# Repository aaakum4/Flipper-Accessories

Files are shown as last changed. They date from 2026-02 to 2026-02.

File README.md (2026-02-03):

# Flipper-Accessories
Now that I have made a custom Flipper, I use create some accessories for it to go with.

A custom expansion board for the Flipper Zero that adds WiFi capability and a high-power IR blaster, designed with safety, flexibility, and future expansion in mind.

This project was designed specifically for my custom Flipper Zero build, which can be found here:
https://github.com/aaakum4/Sorta-Flipper-Zero

While the designs and files are shared openly, they should not be blindly copied or connected to a stock Flipper Zero without understanding the electrical implications. Component choices, power rails, and protection methods were selected with my particular setup and use case in mind.
If you choose to reuse or adapt any part of this project, please make sure it will work with whatever device you are using.

## Overview
This project combines two main subsystems:
- A WiFi board built around the ESP32-S2-WROVER-N4R2 for networking and future firmware experiments
- A 960 nm IR blaster designed for high-power pulsed output while keeping the Flipper electrically isolated

The goal wasn’t just to make something that works, but to make something that’s understandable, modifiable, and safe to plug into a Flipper.

## The WiFi Board
The WiFi side uses the ESP32-S2-WROVER-N4R2, which offered more than enough performance without being unnecessarily complex. Since this board is meant to be reused and extended, several design choices were made with development and debugging in mind:
- Spare GPIO pins left uncommitted for future features
- JTAG and UART exposed for debugging and flashing
- Dedicated BOOT and RESET buttons to avoid relying on awkward software-only recovery

Rather than pushing for maximum performance, the focus here was reliability, ease of development, and not boxing the design into a single use case.

## IR Blaster
The IR blaster uses seven 960 nm IR LEDs, arranged as three series pairs plus one standalone LED, which allowed higher optical output while still working comfortably from a 5 V rail.

A logic-level MOSFET is used for switching instead of a transistor, keeping all high current paths away from the Flipper’s GPIO pins and allowing clean, efficient pulsed operation. The circuit is intended for modulated IR (rather than continuous drive), which makes higher peak currents practical without excessive heat.

This part of the design involved a lot of trade-offs around current, voltage, and safety, and ended up being more conceptually challenging than the WiFi board despite using fewer components.

## Safety & Protection
A core design requirement was ensuring that the Flipper Zero is not put at risk, even in the event of a fault or design mistake. To that end:
- GPIO pins are only ever used as logic-level control signals
- High-current loads are fully isolated using switching components
- Current is limited where appropriate
- No direct power paths exist that could back-feed into the Flipper

The aim was to make the board something you can plug in without constantly worrying about damaging the host device.

## Making the PCB
Here is the final Wifi PCB:




Here is the final IR Blaster PCB:




## BOM
For those interested in the part's I am using, here is the Bill of Materials. It doesnt include the MCU (since it was out of stock when I last check on JLCPCB) and the IR LED's, but any 940nm or 960nm IR LED will do as long as it is 5mm.
Screenshot 2026-02-03 at 1 41 27 pm

## Final Note
Since this is a Flipper project, I feel like I must say that these devices shouldn't be use for any illgeal or unethical activities.

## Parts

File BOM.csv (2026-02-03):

Comment | Designator | Footprint | JLCPCB Part #
100k | R18,R19,R20,R21,R22,R23,R24,R25 | 0201 | C270364
USB_C_Plug | P1 | SMD | C165948
510 | R4 | 0201 | C18164337
100nf | C3,C5 | 0201 | C76934
AZ1117-3.3 | U2 | SOT-223 | C7432020
4.7k | R16,R17 | 0201 | C270346
5.1k | R5,R6 | 0201 | C270344
Si1308EDL | Q1,Q2 | SOT-323 | C7603347
Q_Dual_PNP_PNP_E1B1C2E2B2C1 | Q11,Q6,Q8,Q9 | SOT-363 | C154783
150 | R12,R13,R14,R3 | 0201 | C7467287
D_TVS | D2,D3,D4,D5,D6 | 0201 | C521888
100 | R2 | 0201 | C304499
SW_Push | SW1,SW2 | SMD,3.9x2.9mm | C202388
22uF | C1,C6 | 0603 | C59461
1uF | C4 | 0603 | C15849
LED_RGB | D1 | SMD5050-8P | C6795892
10k | R1,R10,R11,R15 | 0603 | C25804
20 | R7,R8 | 0201 | C320753
Q_PMOS_GSD | Q10,Q12,Q3,Q4,Q5,Q7 | SOT-23-3 | C968645
10uF | C2 | 0603 | C19702
Comment | Designator | Footprint | JLCPCB Part #
5.6 | R2,R3,R4 | 1206 | C137246
Q_NMOS_GSD(RDsON) | Q5 | SOT-23 | C78755
100k | R5 | 603 | C25803
12 | R1 | 1206 | C17913
470 | R7 | 603 | C23179

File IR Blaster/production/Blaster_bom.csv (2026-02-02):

Designator | Footprint | Quantity | Value | LCSC Part #
A1 | Flipper_Zero_Angled | 1 | Flipper_Zero
D1, D2, D3, D4, D5, D6, D7 | LED_D5.0mm | 7 | IR_LED_960nm
Q5 | SOT-23 | 1 | Q_NMOS_GSD (RDs ON)
R1 | 1206 | 1 | 12
R2, R3, R4 | 1206 | 3 | 5.6
R5 | 0603 | 1 | 100k
R7 | 0603 | 1 | 470

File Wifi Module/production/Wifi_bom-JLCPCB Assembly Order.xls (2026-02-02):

JLCPCB BOM Tool - BOM Matching
BOM name：Wifi_bom-JLCPCB Assembly Order.xlsx |  |  | Download Time：2026-02-02 17:04:33 |  |  |  | * Our matching results are updated in real-time, but stock and prices may change. If it's been over 24 hours, please re-match before placing your order.
PCB Assembled Qty：5 |  |  | Est. Total Price：5.3926
Your BOM |  |  |  |  | Matched Parts |  |  |  |  |  |  | Order Information
Top Designator | Bottom Designator | Comment | Footprint | JLCPCB Part # | Matches | Part # | Manufacturer | Footprint | Description | Category | Warning | JLCPCB Part # | Product link | Lib Type | Qty | Source | Total Price ($)
C1,C6 |  | 22uF | 0603 |  | Select by System | CL10A226MQ8NRNC | Samsung Electro-Mechanics | 0603 | 22uF 6.3V X5R ±20% 0603 Multilayer Ceramic Capacitors MLCC - SMD/SMT ROHS | Multilayer Ceramic Capacitors MLCC - SMD/SMT |  | C59461 | https://jlcpcb.com/partdetail/60514-CL10A226MQ8NRNC/C59461 | Basic | 20 | 20 JLCPCB | 0.186
C2 |  | 10uF | 0603 |  | Select by System | CL10A106KP8NNNC | Samsung Electro-Mechanics | 0603 | 10V 10uF X5R ±10% 0603 Multilayer Ceramic Capacitors MLCC - SMD/SMT ROHS | Multilayer Ceramic Capacitors MLCC - SMD/SMT |  | C19702 | https://jlcpcb.com/partdetail/20411-CL10A106KP8NNNC/C19702 | Basic | 20 | 20 JLCPCB | 0.13
C3,C5 |  | 100nf | 0201 |  | Select by System | GRM033R61A104KE15D | Murata Electronics | 0201 | 100nF 10V X5R ±10% 0201 Multilayer Ceramic Capacitors MLCC - SMD/SMT ROHS | Multilayer Ceramic Capacitors MLCC - SMD/SMT |  | C76934 | https://jlcpcb.com/partdetail/MurataElectronics-GRM033R61A104KE15D/C76934 | Extended | 20 | 20 JLCPCB | 0.022
C4 |  | 1uF | 0603 |  | Select by System | CL10A105KB8NNNC | Samsung Electro-Mechanics | 0603 | 1uF 50V X5R ±10% 0603 Multilayer Ceramic Capacitors MLCC - SMD/SMT ROHS | Multilayer Ceramic Capacitors MLCC - SMD/SMT |  | C15849 | https://jlcpcb.com/partdetail/16531-CL10A105KB8NNNC/C15849 | Basic | 20 | 20 JLCPCB | 0.11
D1 |  | LED_RGB | LED_Avago_PLCC6_3x2.8mm |  | Select by Customer | TC5050RGBW3D06-4CSAR3-AFW324A | TCWIN | SMD5050-8P | -40℃~+85℃ 200mW 20mA 2800K~3200K 2V~2.4V、2.8V~3.2V、2.8V~3.2V、2.8V~3.2V 460nm~465nm、515nm~520nm、620nm~625nm 500mcd、700mcd、1.8cd Discrete Diode Red, Emerald Green, Blue, White SMD5050-8P LED Indication - Discrete ROHS | LED Indication - Discrete |  | C784543 | https://jlcpcb.com/partdetail/TCWIN-TC5050RGBW3D06_4CSAR3AFW324A/C784543 | Extended | 2 | 2 JLCPCB | 0.1404
D2,D3,D4,D5,D6 |  | D_TVS | 0201 |  | Select by Customer | ESD3V3U04-0201 | TECH PUBLIC | 0201 | 0.4pF 150nA 16A@8/20us 3.3V 6.5V 8V ESD IEC 61000-4-2、IEC 61000-4-5、IEC 61000-4-4 0201 ESD and Surge Protection (TVS/ESD) ROHS | ESD And Surge Protection (TVS/ESD) |  | C521888 | https://jlcpcb.com/partdetail/TECHPUBLIC-ESD3V3U040201/C521888 | Extended | 20 | 20 JLCPCB | 0.776
P1 |  | USB_C_Plug | USB_C_Receptacle_HRO_TYPE-C-31-M-12 |  | Select by Customer | TYPE-C-31-M-12 | Korean Hroparts Elec | SMD | -30℃~+80℃ 1 10,000 cycles 16P 20V 5A 7.35mm Female Surface Mount, Right Angle Type-C SMD USB Connectors ROHS | USB Connectors |  | C165948 | https://jlcpcb.com/partdetail/Korean_HropartsElec-TYPE_C_31_M12/C165948 | Extended | 2 | 2 JLCPCB | 0.3548
Q1,Q2 |  | Si1308EDL | SOT-323_SC-70 |  | Select by System | SI1308EDL | TECH PUBLIC | SOT-323 | -55℃~+150℃ 1 N-channel 1.4A 1.5V 14.8pF 146pF 150mΩ@4.5V 18.3pF 2.6nC@4.5V 30V 360mW SOT-323 MOSFETs ROHS | MOSFETs |  | C7603347 | https://jlcpcb.com/partdetail/TECHPUBLIC-SI1308EDL/C7603347 | Extended | 8 | 8 JLCPCB | 0.7
Q10,Q12,Q3,Q4,Q5,Q7 |  | Q_PMOS_GSD | SOT-23 |  | Select by Customer | GSD2004S-E3-08 | Vishay Intertech | SOT-23-3 | 1 Pair Series Connection 100nA 1V@100mA 225mA 240V 350mW 4A 50ns SOT-23-3 Switching Diodes ROHS | Switching Diodes |  | C968645 | https://jlcpcb.com/partdetail/VishayIntertech-GSD2004S_E308/C968645 | Extended | 14 | 14 JLCPCB | 1.0752
Q11,Q6,Q8,Q9 |  | Q_Dual_PNP_PNP_E1B1C2E2B2C1 | SOT-363_SC-70-6 |  | Select by Customer | BC857BDW1T1G | onsemi | SOT-363 | -55℃~+150℃ 100MHz 100mA 2 PNP 220 250mW 45V 4uA 5V 650mV PNP SOT-363 Bipolar (BJT) ROHS | Bipolar (BJT) |  | C154783 | https://jlcpcb.com/partdetail/onsemi-BC857BDW1T1G/C154783 | Extended | 12 | 12 JLCPCB | 0.4956
R1,R10,R11,R15 |  | 10k | 0603 |  | Unconfirmed | 0603WAF1002T5E | UNI-ROYAL(Uniroyal Elec) | 0603 | -55℃~+155℃ 100mW 10kΩ 75V Thick Film Resistor ±1% ±100ppm/℃ 0603 Chip Resistor - Surface Mount ROHS | Chip Resistor - Surface Mount | 1.The comment (0603WAF1002T5E) of this part does not match the one (10k) provided in your BOM. Please confirm; | C25804 | https://jlcpcb.com/partdetail/26547-0603WAF1002T5E/C25804 | Basic | 20 | 20 JLCPCB | 0.022
R2 |  | 100 | 0201 |  | Unconfirmed | RC-01W1000FT | FH (Guangdong Fenghua Advanced Tech) | 0201 | -55℃~+125℃ 100Ω 25V 50mW Thick Film Resistor ±1% ±200ppm/℃ 0201 Chip Resistor - Surface Mount ROHS | Chip Resistor - Surface Mount | 1.The comment (RC-01W1000FT) of this part does not match the one (100) provided in your BOM. Please confirm; | C304499 | https://jlcpcb.com/partdetail/288566-RC01W1000FT/C304499 | Extended | 20 | 20 JLCPCB | 0.016
R4 |  | 510 | 0201 |  | Unconfirmed | FRC0201J511 TS | FOJAN | 0201 | -55℃~+125℃ 25V 50mW 510Ω Thick Film Resistor ±200ppm/℃ ±5% 0201 Chip Resistor - Surface Mount ROHS | Chip Resistor - Surface Mount | 1.The comment (FRC0201J511 TS) of this part does not match the one (510) provided in your BOM. Please confirm; | C18164337 | https://jlcpcb.com/partdetail/FOJAN-FRC0201J511TS/C18164337 | Extended | 20 | 20 JLCPCB | 0.012
R5,R6 |  | 5.1k | 0201 |  | Unconfirmed | 0201WMF5101TEE | UNI-ROYAL(Uniroyal Elec) | 0201 | -55℃~+155℃ 25V 5.1kΩ 50mW Thick Film Resistor ±1% ±200ppm/℃ 0201 Chip Resistor - Surface Mount ROHS | Chip Resistor - Surface Mount | 1.The comment (0201WMF5101TEE) of this part does not match the one (5.1k) provided in your BOM. Please confirm; | C270344 | https://jlcpcb.com/partdetail/259874-0201WMF5101TEE/C270344 | Extended | 20 | 20 JLCPCB | 0.016
R7,R8 |  | 20 | 0201 |  | Unconfirmed | RC-01W20R0FT | FH (Guangdong Fenghua Advanced Tech) | 0201 | -55℃~+125℃ 20Ω 25V 50mW Thick Film Resistor ±1% ±200ppm/℃ 0201 Chip Resistor - Surface Mount ROHS | Chip Resistor - Surface Mount | 1.The comment (RC-01W20R0FT) of this part does not match the one (20) provided in your BOM. Please confirm; | C320753 | https://jlcpcb.com/partdetail/301658-RC01W20R0FT/C320753 | Extended | 20 | 20 JLCPCB | 0.014
R12,R13,R14,R3 |  | 150 | 0201 |  | Unconfirmed | FRC0201F1500TS | FOJAN | 0201 | 150Ω 50mW Thick Film Resistor ±1% ±200ppm/℃ 0201 Chip Resistor - Surface Mount | Chip Resistor - Surface Mount | 1.The comment (FRC0201F1500TS) of this part does not match the one (150) provided in your BOM. Please confirm; | C7467287 | https://jlcpcb.com/partdetail/FOJAN-FRC0201F1500TS/C7467287 | Extended | 20 | 20 JLCPCB | 0.014
R16,R17 |  | 4.7k | 0201 |  | Unconfirmed | 0201WMF4701TEE | UNI-ROYAL(Uniroyal Elec) | 0201 | -55℃~+155℃ 25V 4.7kΩ 50mW Thick Film Resistor ±1% ±200ppm/℃ 0201 Chip Resistor - Surface Mount ROHS | Chip Resistor - Surface Mount | 1.The comment (0201WMF4701TEE) of this part does not match the one (4.7k) provided in your BOM. Please confirm; | C270346 | https://jlcpcb.com/partdetail/259876-0201WMF4701TEE/C270346 | Extended | 20 | 20 JLCPCB | 0.016
R18,R19,R20,R21,R22,R23,R24,R25 |  | 100k | 0201 |  | Unconfirmed | 0201WMF1003TEE | UNI-ROYAL(Uniroyal Elec) | 0201 | -55℃~+155℃ 100kΩ 25V 50mW Thick Film Resistor ±1% ±200ppm/℃ 0201 Chip Resistor - Surface Mount ROHS | Chip Resistor - Surface Mount | 1.The comment (0201WMF1003TEE) of this part does not match the one (100k) provided in your BOM. Please confirm; | C270364 | https://jlcpcb.com/partdetail/259894-0201WMF1003TEE/C270364 | Extended | 28 | 28 JLCPCB | 0.0224
SW1,SW2 |  | SW_Push | SW_Push_SPST_NO_Alps_SKRK |  | Select by Customer | SKRKAHE020 | ALPSALPINE | SMD,3.9x2.9mm | -40℃~+85℃ 12V 1N 2.9mm 200,000 Cycles 2mm 3.9mm 50mA Round Button SMD(SMT) Tab SPST-NO Surface Mount,Vertical SMD,3.9x2.9mm Tactile Switches ROHS | Tactile Switches |  | C202388 | https://jlcpcb.com/partdetail/ALPSALPINE-SKRKAHE020/C202388 | Extended | 6 | 6 JLCPCB | 1.0242
U2 |  | AZ1117-3.3 | SOT-223 |  | Select by Customer | A1117-3.3 | IDCHIP | SOT-223 | -40℃~+125℃@(Ta) 1 1.2V@(1A) 15V 1A 3.3V 5mA 60dB@(120Hz) Fixed Over Current Protection、Over Temperature Protection Positive SOT-223 Voltage Regulators - Linear, Low Drop Out (LDO) Regulators ROHS | Voltage Regulators - Linear, Low Drop Out (LDO) Regulators |  | C7432020 | https://jlcpcb.com/partdetail/IDCHIP-A1117_33/C7432020 | Extended | 6 | 6 JLCPCB | 0.246
U1 |  | ESP32-S2-WROVER | ESP32-S2-WROVER |  | Unconfirmed | ESP32-S2-WROVER-N4R2 | Espressif Systems | SMD,18x31mm | SMD,18x31mm WiFi Modules ROHS | WiFi Modules | 1.The comment (ESP32-S2-WROVER-N4R2) of this part does not match the one (ESP32-S2-WROVER) provided in your BOM. Please confirm; | C967027 | https://jlcpcb.com/partdetail/1053299-ESP32_S2_WROVERN4R2/C967027 | Extended | 2 | 0 JLCPCB | 0
A1 |  | Flipper_Zero | Flipper_Zero_Angled |  | No matches | No Part Selected

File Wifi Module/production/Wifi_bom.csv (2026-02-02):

Designator | Footprint | Quantity | Value | LCSC Part #
A1 | Flipper_Zero_Angled | 1 | Flipper_Zero
C1, C6 | 0603 | 2 | 22uF
C2 | 0603 | 1 | 10uF
C3, C5 | 0201 | 2 | 100nf
C4 | 0603 | 1 | 1uF
D1 | LED_Avago_PLCC6_3x2.8mm | 1 | LED_RGB
D2, D3, D4, D5, D6 | 0201 | 5 | D_TVS
P1 | USB_C_Receptacle_HRO_TYPE-C-31-M-12 | 1 | USB_C_Plug
Q1, Q2 | SOT-323_SC-70 | 2 | Si1308EDL
Q10, Q12, Q3, Q4, Q5, Q7 | SOT-23 | 6 | Q_PMOS_GSD
Q11, Q6, Q8, Q9 | SOT-363_SC-70-6 | 4 | Q_Dual_PNP_PNP_E1B1C2E2B2C1
R1, R10, R11, R15 | 0603 | 4 | 10k
R12, R13, R14, R3 | 0201 | 4 | 150
R16, R17 | 0201 | 2 | 4.7k
R18, R19, R20, R21, R22, R23, R24, R25 | 0201 | 8 | 100k
R2 | 0201 | 1 | 100
R4 | 0201 | 1 | 510
R5, R6 | 0201 | 2 | 5.1k
R7, R8 | 0201 | 2 | 20
SW1, SW2 | SW_Push_SPST_NO_Alps_SKRK | 2 | SW_Push
U1 | ESP32-S2-WROVER | 1 | ESP32-S2-WROVER
U2 | SOT-223 | 1 | AZ1117-3.3

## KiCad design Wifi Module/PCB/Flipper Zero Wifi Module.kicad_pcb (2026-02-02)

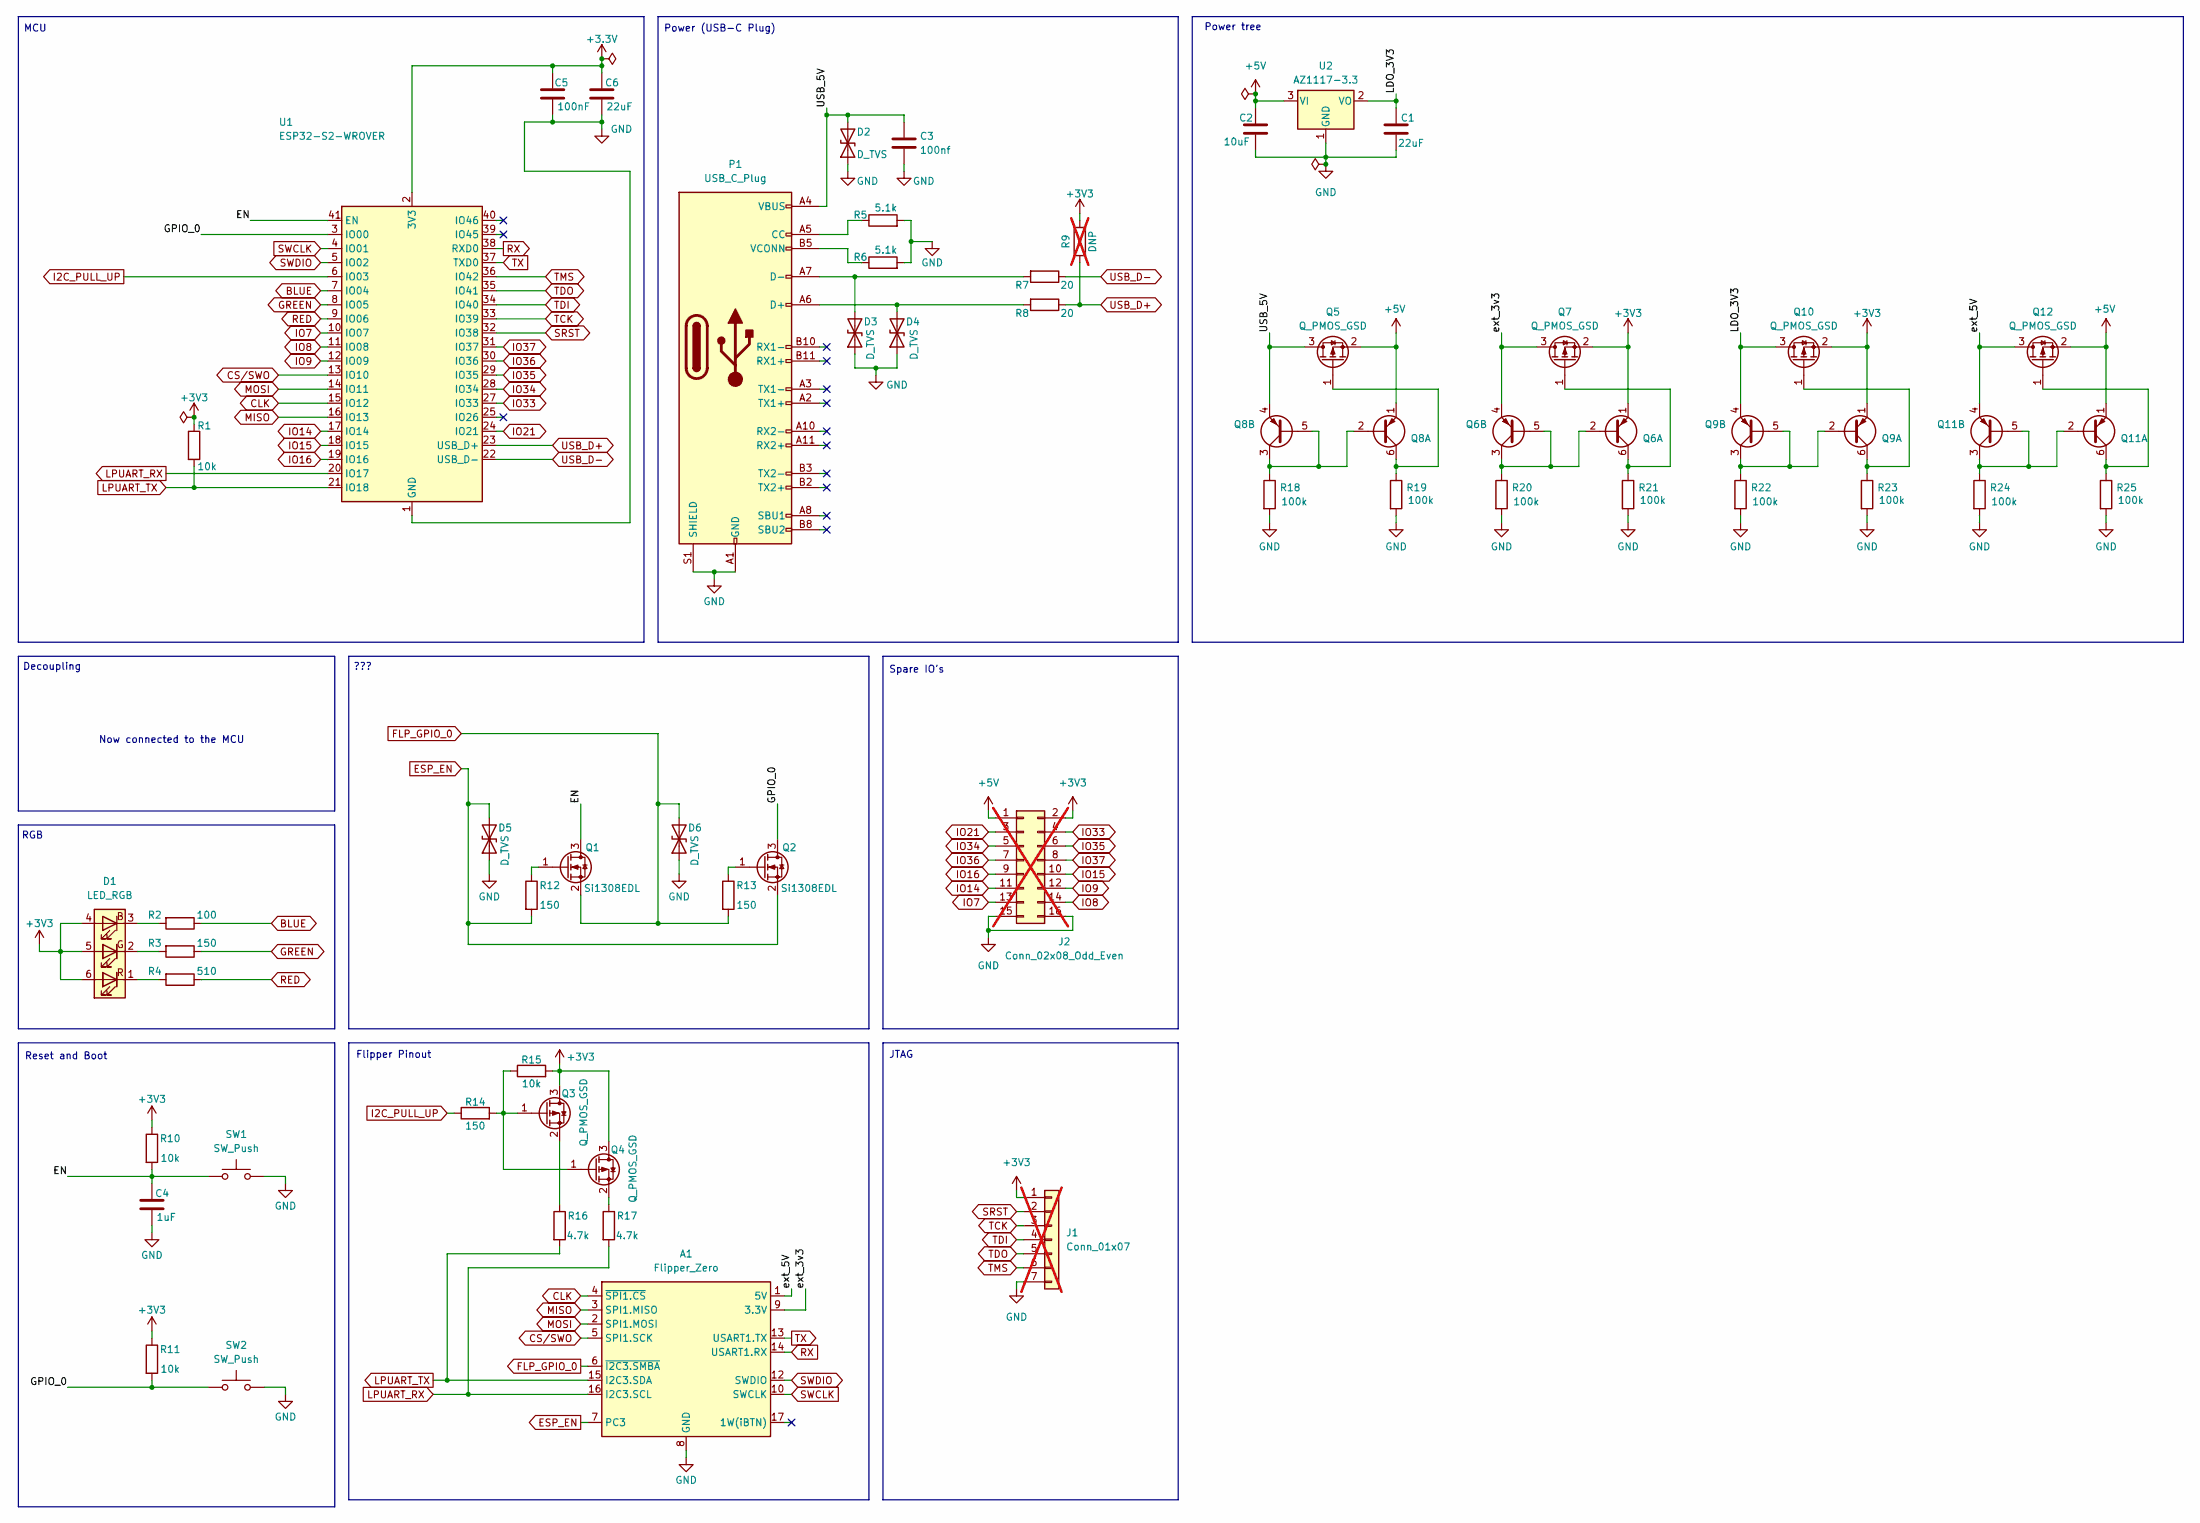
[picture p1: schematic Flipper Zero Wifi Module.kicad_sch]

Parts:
A1: Flipper_Zero; Flipper_Zero_Angled
C1, C6: 22uF; C_0603_1608Metric
C2: 10uF; C_0603_1608Metric
C3: 100nf; C_0603_1608Metric
C4: 1uF; C_0603_1608Metric
C5: 100nF; C_0603_1608Metric
D1: LED_RGB; LED_Avago_PLCC6_3x2.8mm
D2, D3, D4, D5, D6: D_TVS; D_0201_0603Metric
J1: Conn_01x07; PinHeader_1x07_P2.54mm_Vertical; not fitted
J2: Conn_02x08_Odd_Even; PinHeader_2x08_P2.54mm_Vertical; not fitted
P1: USB_C_Plug; USB_C_Receptacle_HRO_TYPE-C-31-M-12
Q1, Q2: Si1308EDL; SOT-323_SC-70
Q3, Q4, Q5, Q7, Q10, Q12: Q_PMOS_GSD; SOT-23
Q6, Q8, Q9, Q11: Q_Dual_PNP_PNP_E1B1C2E2B2C1; SOT-363_SC-70-6
R1, R10, R11, R15: 10k; R_0603_1608Metric
R2: 100; R_0603_1608Metric
R3, R12, R13, R14: 150; R_0603_1608Metric
R4: 510; R_0603_1608Metric
R5, R6: 5.1k; R_0603_1608Metric
R7, R8: 20; R_0603_1608Metric
R9: DNP; R_0603_1608Metric; not fitted
R16, R17: 4.7k; R_0603_1608Metric
R18, R19, R20, R21, R22, R23, R24, R25: 100k; R_0603_1608Metric
SW1, SW2: SW_Push; SW_PUSH_6mm
U1: ESP32-S2-WROVER
U2: AZ1117-3.3; SOT-223

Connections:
+3.3V: C5.1, C6.1, U1.2 (3V3)
+3V3: D1.4 (BA), D1.5 (GA), D1.6 (RA), J1.1, J2.2, Q3.3 (D), Q4.3 (D), Q6.1 (E1), Q7.2 (S), Q9.1 (E1), Q10.2 (S), R1.1, R9.1, R10.1, R11.1, R15.2
+5V: C2.1, J2.1, Q5.2 (S), Q8.1 (E1), Q11.1 (E1), Q12.2 (S), U2.3 (VI)
/EN: C4.1, Q1.3 (D), R10.2, SW1.1, U1.41 (EN)
/GPIO_0: Q2.3 (D), R11.2, SW2.1, U1.3 (IO00)
/LDO_3V3: C1.1, Q9.4 (E2), Q10.3 (D), U2.2 (VO)
/USB_5V: C3.1, D2.2 (A2), P1.A4 (VBUS), P1.A9 (VBUS), P1.B4 (VBUS), P1.B9 (VBUS), Q5.3 (D), Q8.4 (E2)
/ext_3v3: A1.9 (3.3V), Q6.4 (E2), Q7.3 (D)
/ext_5V: A1.1 (5V), Q11.4 (E2), Q12.3 (D)
BLUE: R2.1, U1.7 (IO04)
CLK: A1.4 (~SPI1.CS), U1.15 (IO12)
CS/SWO: A1.5 (SPI1.SCK), U1.13 (IO10)
ESP_EN: A1.7 (PC3), D5.2 (A2), Q2.2 (S), R12.2
FLP_GPIO_0: A1.6 (~I2C3.SMBA), D6.2 (A2), Q1.2 (S), R13.2
GND: A1.8 (GND), A1.11 (GND), A1.18 (GND), C1.2, C2.2, C3.2, C4.2, C5.2, C6.2, D2.1 (A1), D3.1 (A1), D4.1 (A1), D5.1 (A1), D6.1 (A1), J1.7, J2.15, J2.16, P1.A1 (GND), P1.A12 (GND), P1.B1 (GND), P1.B12 (GND), P1.S1 (SHIELD), R5.2, R6.2, R18.2, R19.2, R20.2, R21.2, R22.2, R23.2, R24.2, R25.2, SW1.2, SW2.2, U1.1 (GND), U1.26 (GND), U1.42 (GND), U1.43 (GND), U2.1 (GND)
GREEN: R3.1, U1.8 (IO05)
I2C_PULL_UP: R14.1, U1.6 (IO03)
IO7: J2.13, U1.10 (IO07)
IO8: J2.14, U1.11 (IO08)
IO9: J2.12, U1.12 (IO09)
IO14: J2.11, U1.17 (IO14)
IO15: J2.10, U1.18 (IO15)
IO16: J2.9, U1.19 (IO16)
IO21: J2.3, U1.24 (IO21)
IO33: J2.4, U1.27 (IO33)
IO34: J2.5, U1.28 (IO34)
IO35: J2.6, U1.29 (IO35)
IO36: J2.7, U1.30 (IO36)
IO37: J2.8, U1.31 (IO37)
LPUART_RX: A1.16 (I2C3.SCL), R17.2, U1.20 (IO17)
LPUART_TX: A1.15 (I2C3.SDA), R1.2, R16.2, U1.21 (IO18)
MISO: A1.3 (SPI1.MISO), U1.16 (IO13)
MOSI: A1.2 (SPI1.MOSI), U1.14 (IO11)
unnamed: D1.3 (BK), R2.2
unnamed: D1.2 (GK), R3.2
unnamed: D1.1 (RK), R4.2
unnamed: P1.A5 (CC), R5.1
unnamed: P1.B5 (VCONN), R6.1
unnamed: Q1.1 (G), R12.1
unnamed: Q2.1 (G), R13.1
unnamed: Q3.1 (G), Q4.1 (G), R14.2, R15.1
unnamed: Q3.2 (S), R16.1
unnamed: Q4.2 (S), R17.1
unnamed: Q5.1 (G), Q8.6 (C1), R19.1
unnamed: Q6.2 (B1), Q6.3 (C2), Q6.5 (B2), R20.1
unnamed: Q6.6 (C1), Q7.1 (G), R21.1
unnamed: Q8.2 (B1), Q8.3 (C2), Q8.5 (B2), R18.1
unnamed: Q9.2 (B1), Q9.3 (C2), Q9.5 (B2), R22.1
unnamed: Q9.6 (C1), Q10.1 (G), R23.1
unnamed: Q11.2 (B1), Q11.3 (C2), Q11.5 (B2), R24.1
unnamed: Q11.6 (C1), Q12.1 (G), R25.1
RED: R4.1, U1.9 (IO06)
RX: A1.14 (USART1.RX), U1.38 (RXD0)
SRST: J1.2, U1.32 (IO38)
SWCLK: A1.10 (SWCLK), U1.4 (IO01)
SWDIO: A1.12 (SWDIO), U1.5 (IO02)
TCK: J1.3, U1.33 (IO39)
TDI: J1.4, U1.34 (IO40)
TDO: J1.5, U1.35 (IO41)
TMS: J1.6, U1.36 (IO42)
TX: A1.13 (USART1.TX), U1.37 (TXD0)

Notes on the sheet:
Flipper Pinout
Reset and Boot
Now connected to the MCU
???
Spare IO's
MCU
Power (USB-C Plug)
JTAG
Decoupling
RGB
Power tree

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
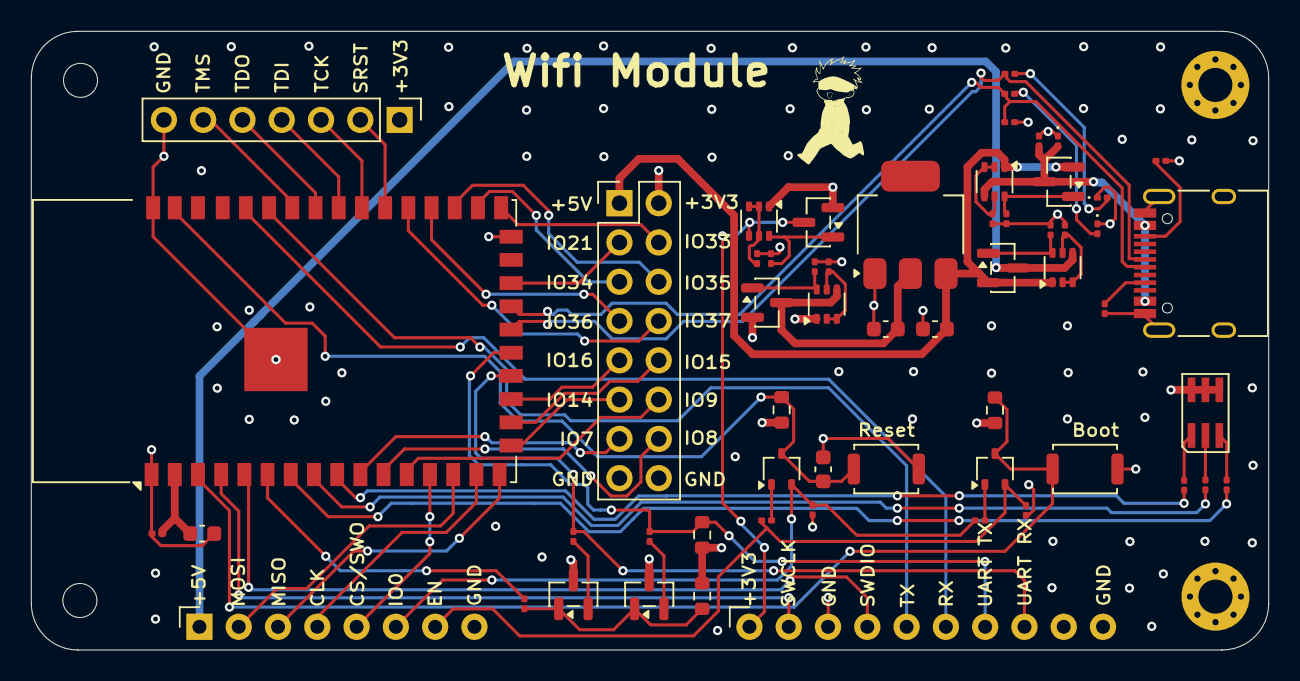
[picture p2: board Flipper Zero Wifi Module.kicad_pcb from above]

Board: 4 copper layers, 80.0 x 40.0 mm, 57 parts (0 on the bottom side), 65 nets.

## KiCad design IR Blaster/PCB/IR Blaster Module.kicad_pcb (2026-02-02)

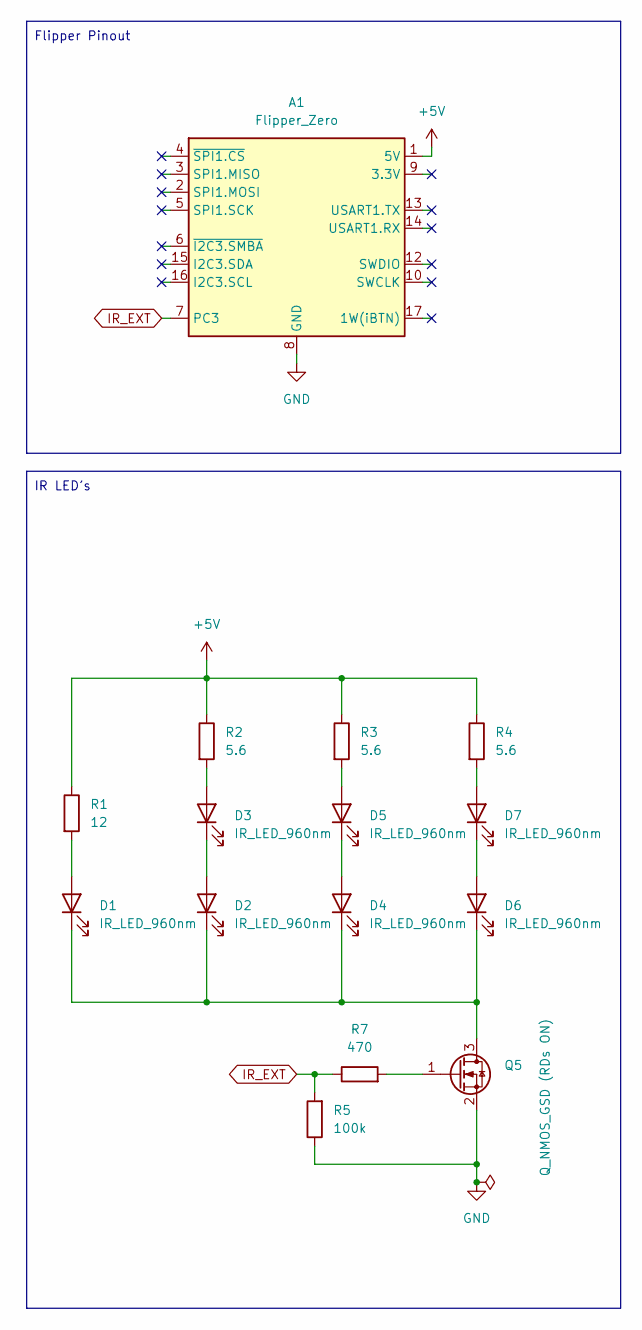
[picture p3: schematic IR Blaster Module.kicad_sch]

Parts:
A1: Flipper_Zero; Flipper_Zero_Angled
D1, D2, D3, D4, D5, D6, D7: IR_LED_960nm; LED_D5.0mm
Q5: Q_NMOS_GSD (RDs ON); SOT-23
R1: 12; R_1206_3216Metric
R2, R3, R4: 5.6; R_1206_3216Metric
R5: 100k; R_0603_1608Metric
R7: 470; R_0603_1608Metric

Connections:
+5V: A1.1 (5V), R1.1, R2.1, R3.1, R4.1
GND: A1.8 (GND), A1.11 (GND), A1.18 (GND), Q5.2 (S), R5.1
IR_EXT: A1.7 (PC3), R5.2, R7.1
unnamed: D1.2 (A), R1.2
unnamed: D1.1 (K), D2.1 (K), D4.1 (K), D6.1 (K), Q5.3 (D)
unnamed: D2.2 (A), D3.1 (K)
unnamed: D3.2 (A), R2.2
unnamed: D4.2 (A), D5.1 (K)
unnamed: D5.2 (A), R3.2
unnamed: D6.2 (A), D7.1 (K)
unnamed: D7.2 (A), R4.2
unnamed: Q5.1 (G), R7.2

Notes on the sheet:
Flipper Pinout
IR LED's

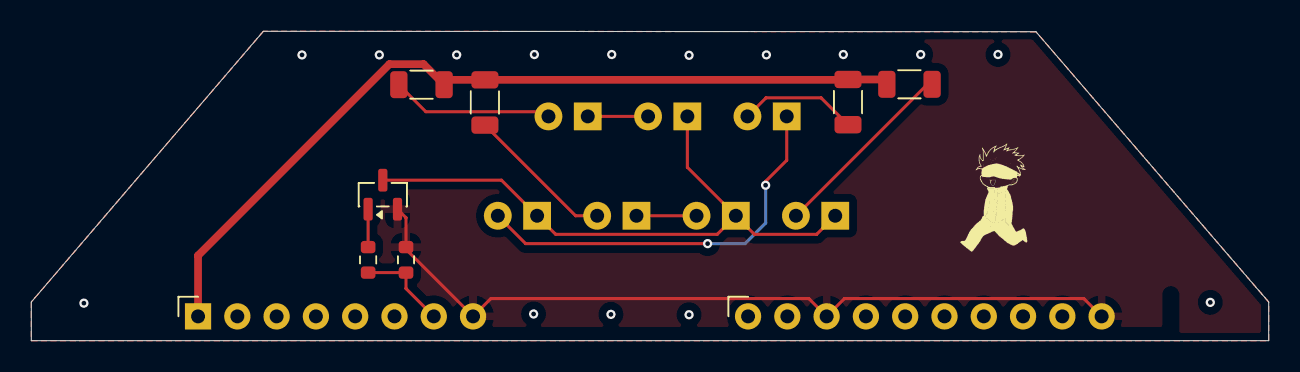
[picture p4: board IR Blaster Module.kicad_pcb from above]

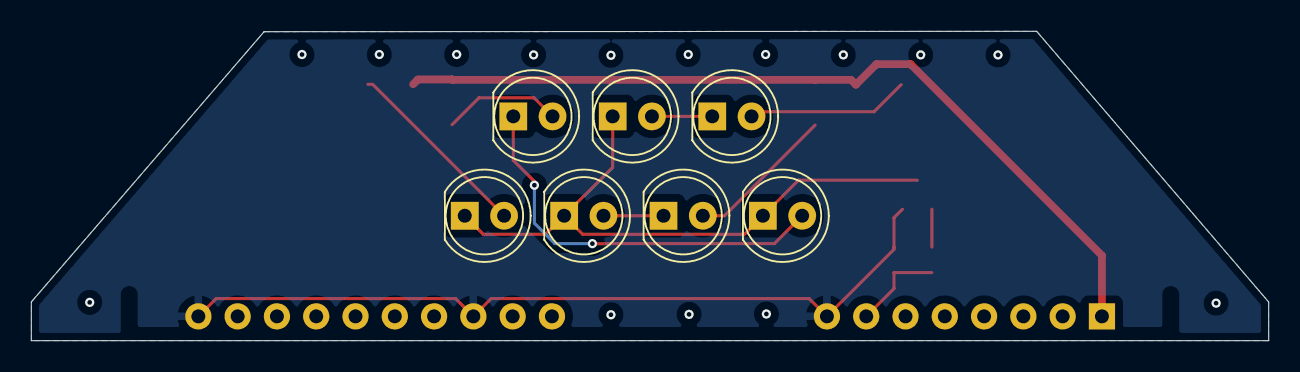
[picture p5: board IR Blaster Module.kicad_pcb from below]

Board: 2 copper layers, 80.0 x 20.0 mm, 15 parts (7 on the bottom side), 12 nets.

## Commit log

2026-01-30 Enhance README with project overview and details
    Expanded the README to include detailed descriptions of the WiFi board, IR blaster, and safety features.
2026-01-30 Added schematic files for the IR Blaster and Wifi Module
    [Flipper Zero Wifi Module.kicad_sch, IR Blaster Module.kicad_sch]
2026-02-02 Update README with final PCB images
    Added images of final Wifi and IR Blaster PCBs.
2026-02-02 Added PCB Files and Production Files
    [Blaster_bom.csv, Blaster_designators.csv, Blaster_positions.csv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]
2026-02-03 Update README with BOM and final note
    Added BOM section and final note to README.
